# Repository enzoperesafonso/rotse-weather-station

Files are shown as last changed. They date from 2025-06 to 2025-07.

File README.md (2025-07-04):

# Open Observatory Weather Station

Open-source, low-cost weather station designed for remote astronomical observatories

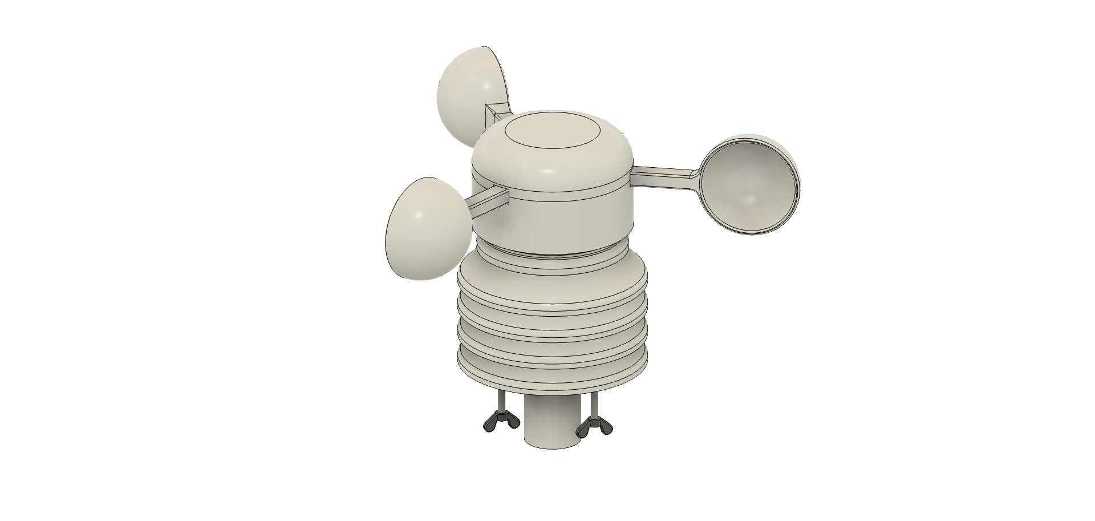
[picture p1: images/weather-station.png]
Weather Station


## Overview

A complete weather monitoring solution built specifically for astronomical observatories and remote telescope installations. This project provides everything needed to build and deploy a professional-grade weather station at a fraction of commercial costs.

Originally developed to support the ROTSE-III Namibia telescope revival project, but designed as a general-purpose solution for the global astronomy community.

## Features

- **Comprehensive Sensor Suite**: Temperature, humidity, barometric pressure, wind speed.
- **3D Printable Design**: Weatherproof enclosure and mounting hardware
- **Remote Monitoring**: Web interface with real-time data display
- **Data Logging**: CSV/JSON export with API access
- **Solar Power Ready**: Designed for off-grid installations
- **Robust Construction**: Built to withstand harsh outdoor environments

## Hardware Design

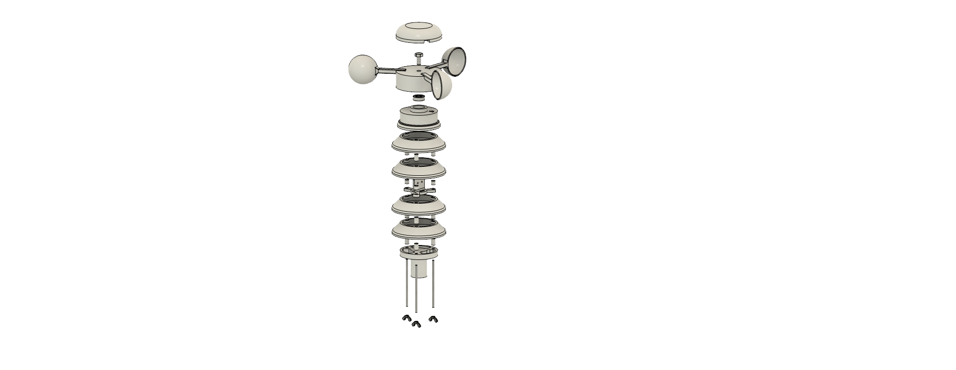
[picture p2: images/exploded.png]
Cutaway View


The weather station features a modular design with a weatherproof 3D printed enclosure. All components are easily accessible for maintenance while providing excellent protection against the elements.

## Quick Start

1. **Hardware**: Print the enclosure parts and assemble with components from the BOM
2. **Software**: Flash the firmware and configure your WiFi settings
3. **Deploy**: Mount securely and connect to your observatory network
4. **Monitor**: Access the web interface for real-time data and historical logs

## Repository Structure

- `hardware/` - 3D models, electronics schematics, and assembly instructions
- `software/` - Firmware, web interface, and calibration tools
- `docs/` - Detailed assembly guide, setup instructions, and troubleshooting
- `examples/` - Sample configurations and data outputs

## Getting Started

See the [Assembly Guide](docs/assembly-guide.md) for detailed build instructions and the [Software Setup](docs/software-setup.md) guide for firmware installation.

## License

This project is open source. See [LICENSE](LICENSE) for details.

## Acknowledgments

This project was developed to support the revival of the ROTSE-III telescope network and is dedicated to making low cost professional-grade weather monitoring accessible to observatories worldwide.

---

⭐ If this project helps your observatory, please consider starring the repository!

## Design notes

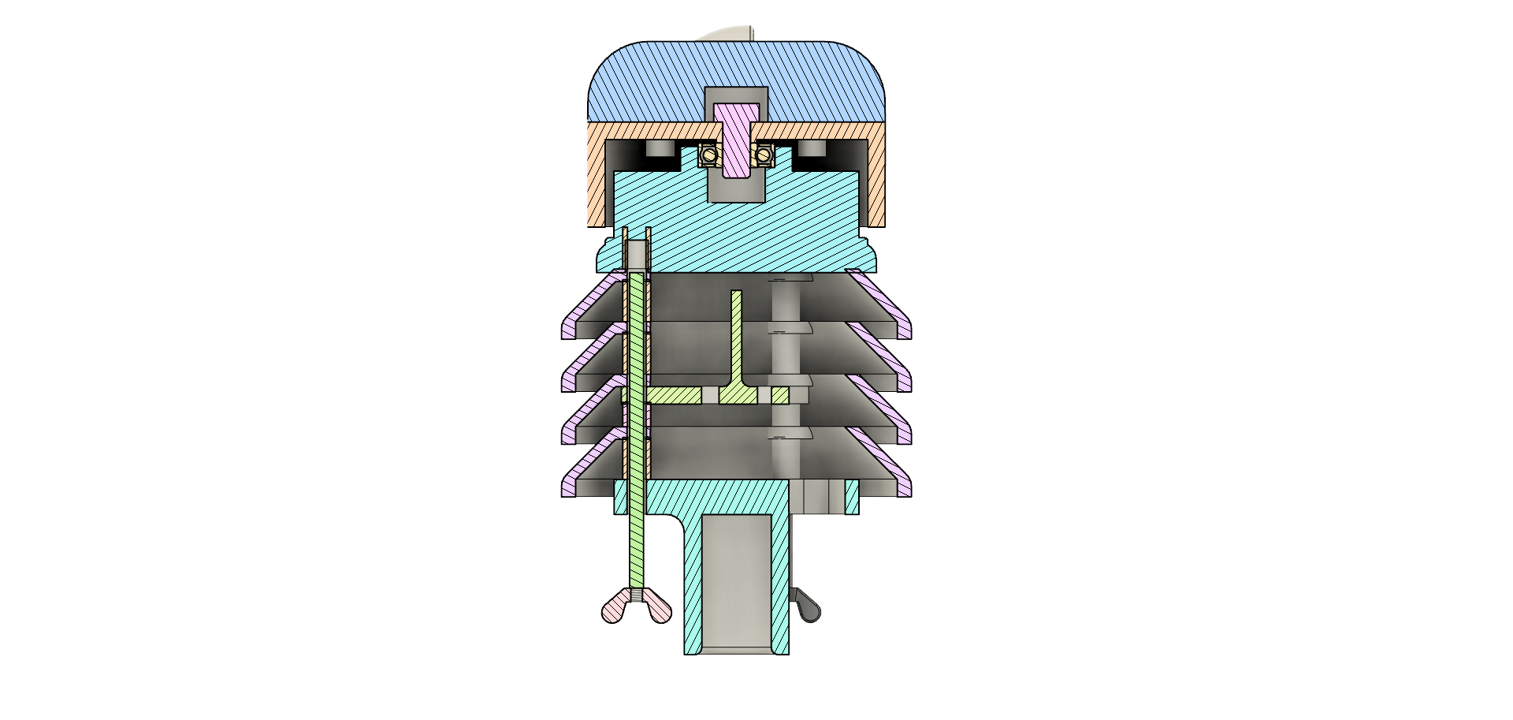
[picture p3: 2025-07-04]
images/cutaway.png

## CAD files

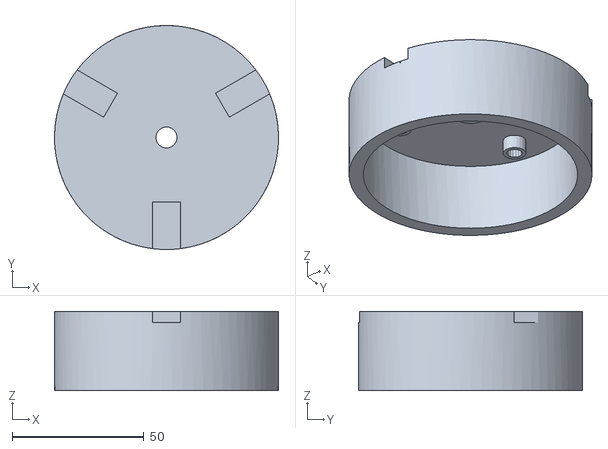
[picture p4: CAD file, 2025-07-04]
hardware/enclosure/3d-print-files/rotor.stl
85.0 x 85.0 x 30.0

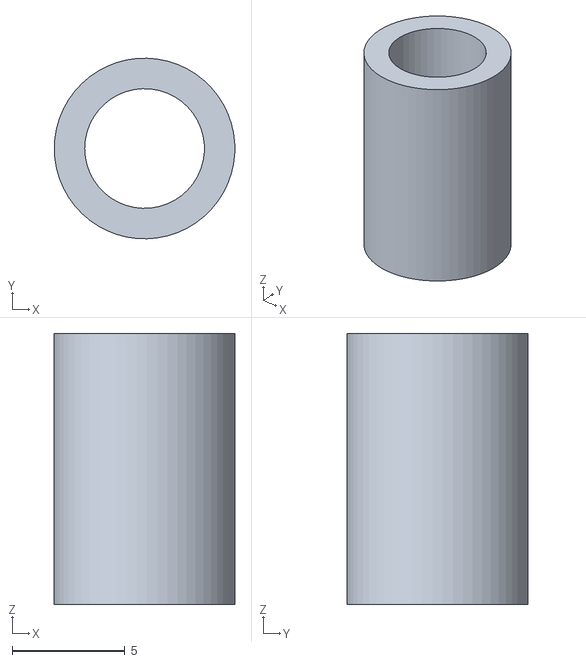
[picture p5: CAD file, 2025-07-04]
hardware/enclosure/3d-print-files/tall-spacer.stl
7.99 x 8.00 x 12.0

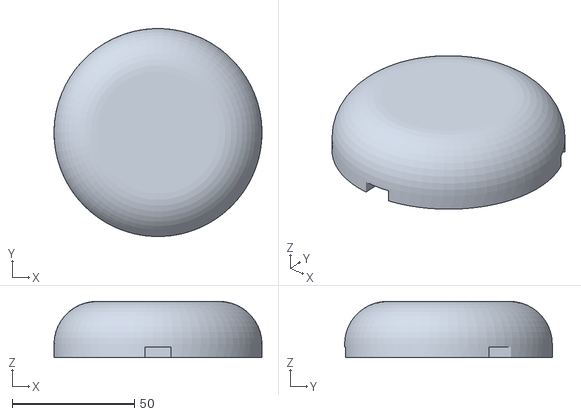
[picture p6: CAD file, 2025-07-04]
hardware/enclosure/3d-print-files/rotor-cap.stl
85.0 x 85.0 x 23.0

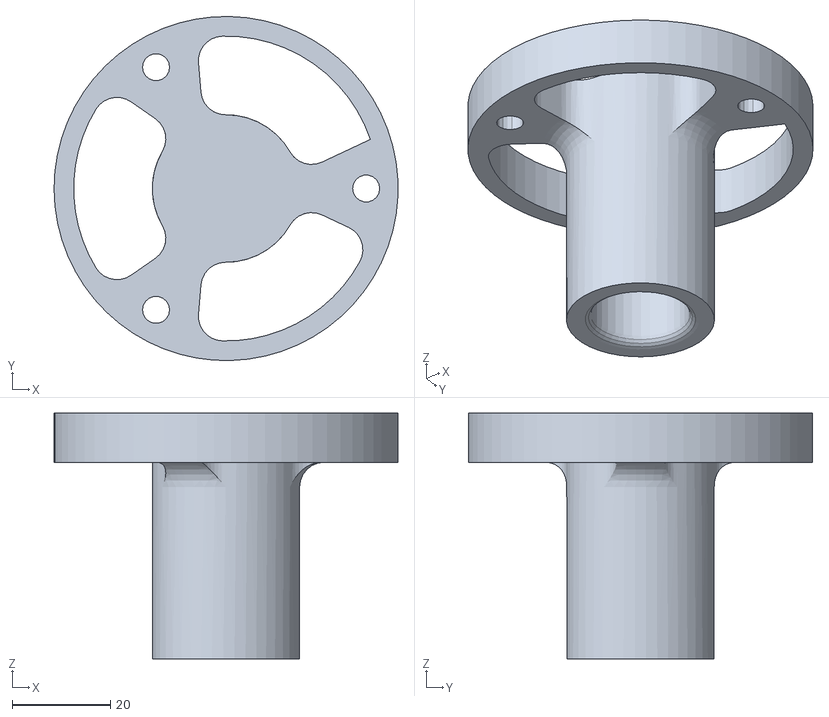
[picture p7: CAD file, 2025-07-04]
hardware/enclosure/3d-print-files/base.stl
70.0 x 70.0 x 50.0

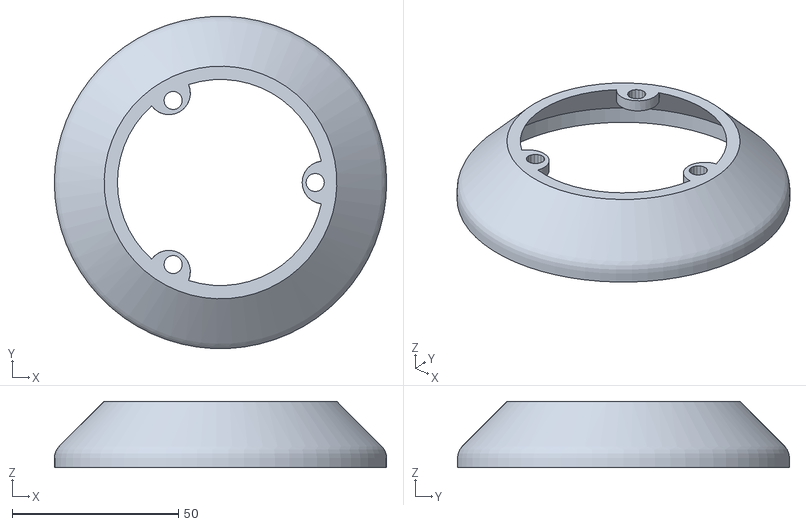
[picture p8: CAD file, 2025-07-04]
hardware/enclosure/3d-print-files/radiation-screen.stl
100.0 x 99.9 x 20.0

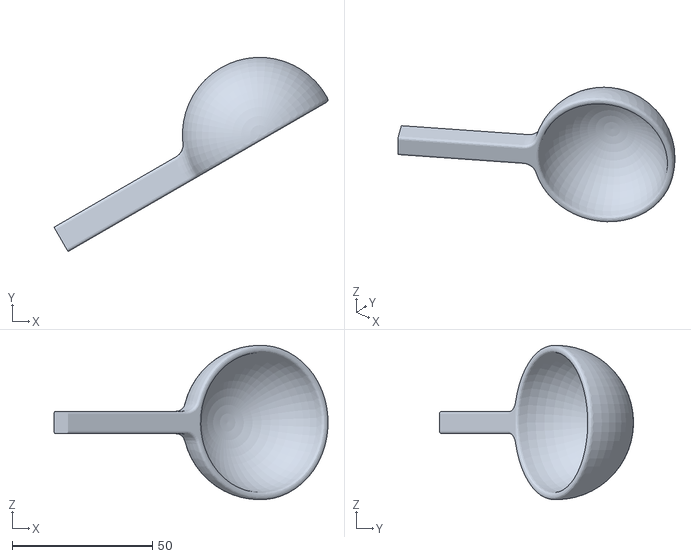
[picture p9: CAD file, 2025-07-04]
hardware/enclosure/3d-print-files/cup.stl
97.7 x 69.2 x 55.0

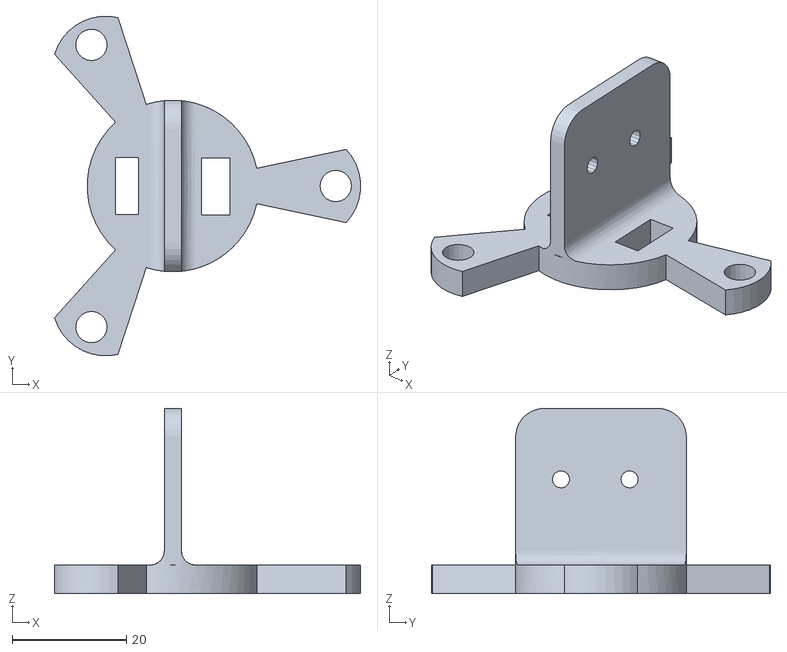
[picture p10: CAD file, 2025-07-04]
hardware/enclosure/3d-print-files/sensor-holder.stl
53.5 x 59.4 x 32.4

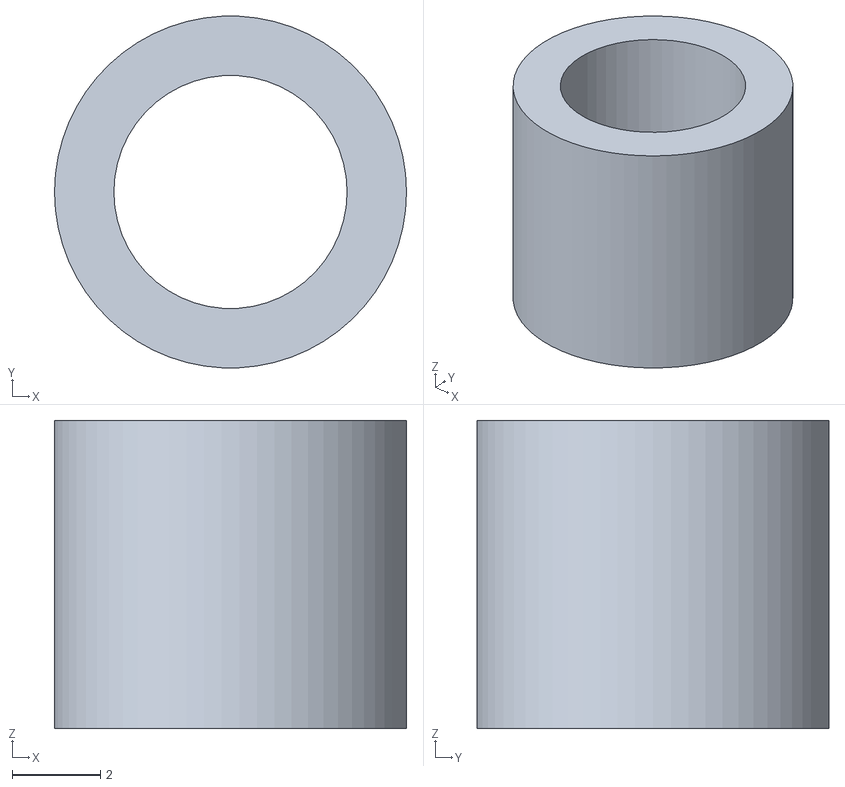
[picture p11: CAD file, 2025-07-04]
hardware/enclosure/3d-print-files/short-spacer.stl
8.00 x 7.99 x 7.00

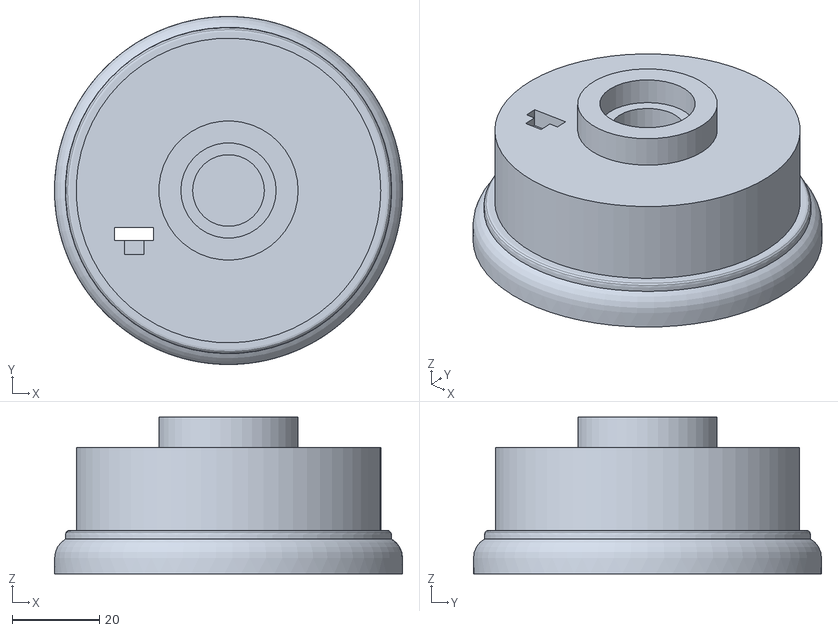
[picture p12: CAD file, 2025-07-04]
hardware/enclosure/3d-print-files/roof.stl
80.0 x 80.0 x 36.0

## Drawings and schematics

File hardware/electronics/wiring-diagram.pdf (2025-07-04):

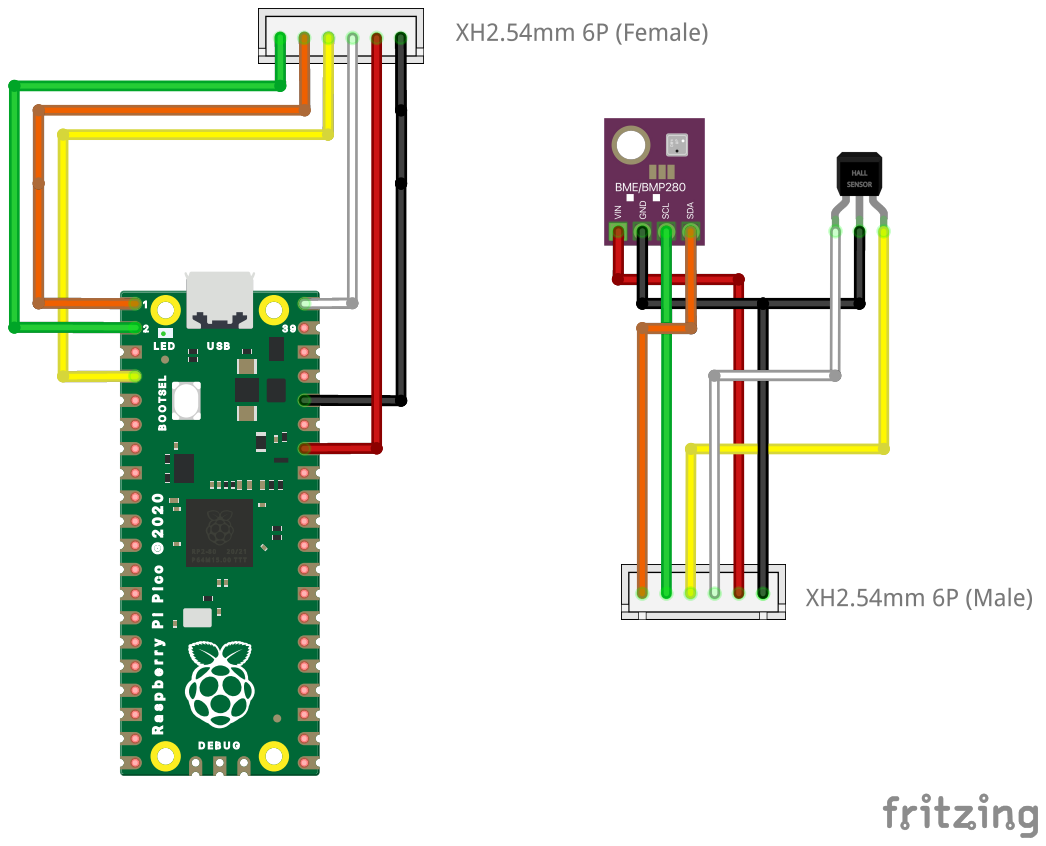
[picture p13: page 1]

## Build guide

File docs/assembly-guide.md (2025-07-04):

# Weather Station Assembly Guide

*Complete hardware and electronics assembly instructions for the Open Observatory Weather Station*

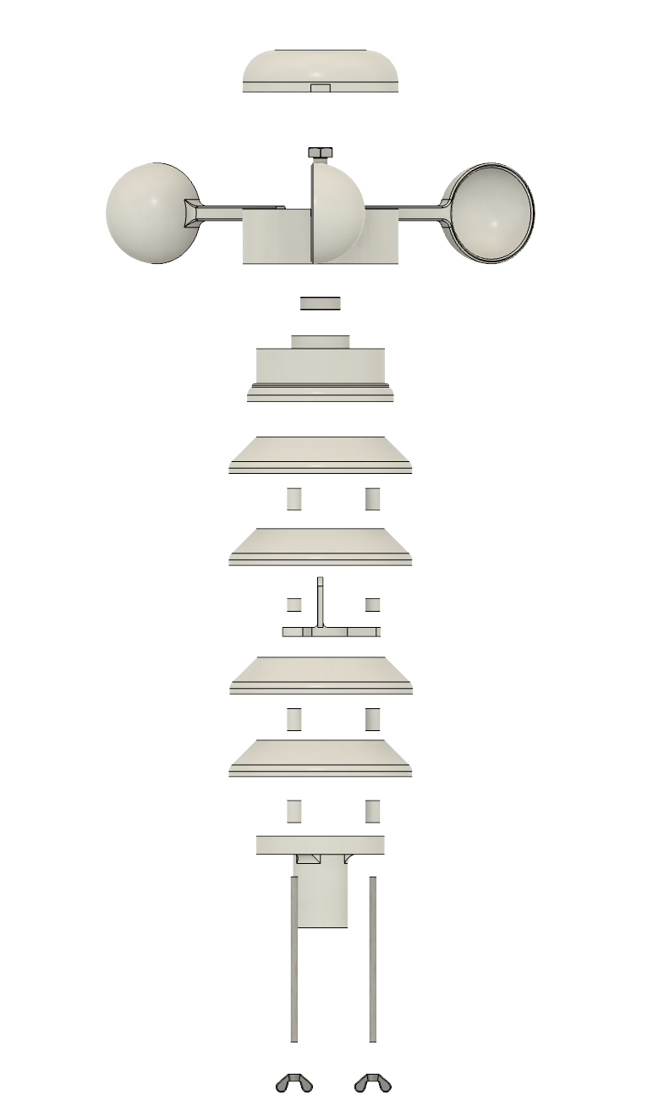
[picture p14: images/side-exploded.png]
ROTSE Weather Station Exploded View


## Bill of Materials

### 3D Printed Parts
- 1x Base
- 1x Roof  
- 1x Sensor Holder
- 4x Radiation Screens
- 1x Rotor
- 1x Rotor Cap
- 3x Cup 
- 12x Tall spacer
- 3x Short spacer

### Hardware Components
- 1x M8 x 16 Steel hex head bolt
- 1x M8 Nut
- 3x M4 Steel wing nuts
- 3x Steel rod M4 (10cm length)
- 1x Ball bearing (permanently lubricated)
- 3x Neodymium magnets (5x5mm)

### Electronics
- 1x Raspberry Pi Pico
- 1x AHT20 + BMP280 Temperature, Humidity, and Pressure Module
- 1x Hall Effect Sensor A3144 
- MicroUSB cable for programming
- 2x XH2.54 4P Male Connector (Recommended)
- 2x XH2.54 4P Female Connector (Recommended)
- 1x Double Side Prototype PCB Universal Printed Circuit Board (3x7cm) (Recommended)
- 4m 6-core cable (Recommended)

## Tools Required
- 3D printer (PLA or PETG recommended)
- Soldering iron and solder
- Wire strippers
- Small screwdriver set
- Drill with small bits
- Multimeter (for testing)

## Assembly Instructions

### Step 1: Rotor Assembly
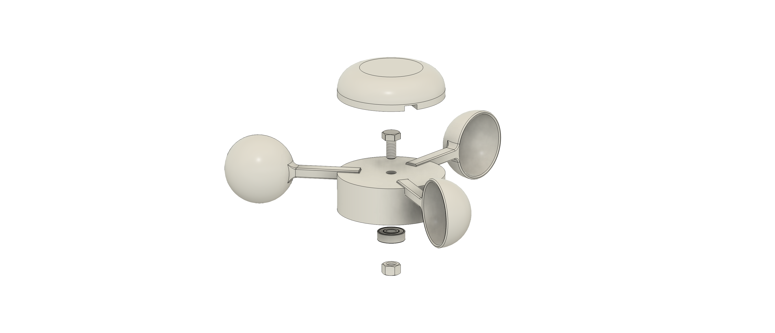
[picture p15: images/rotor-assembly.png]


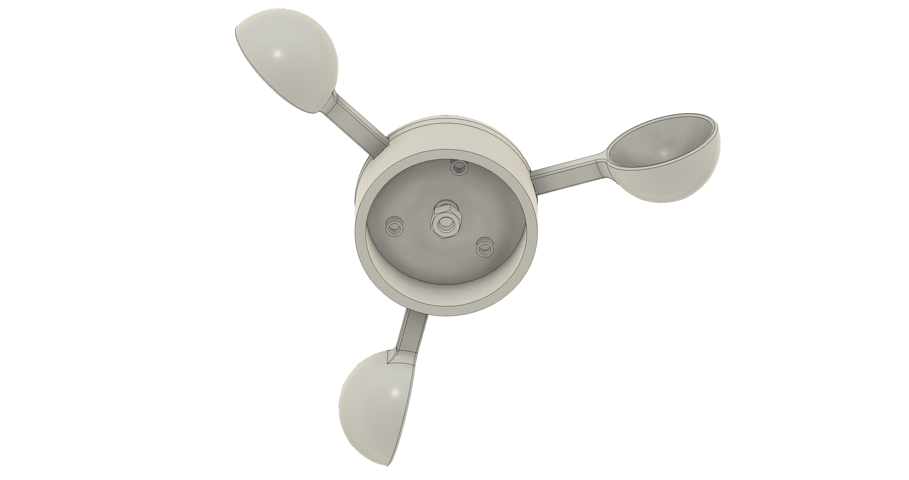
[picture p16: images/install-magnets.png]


### Step 2: Roof
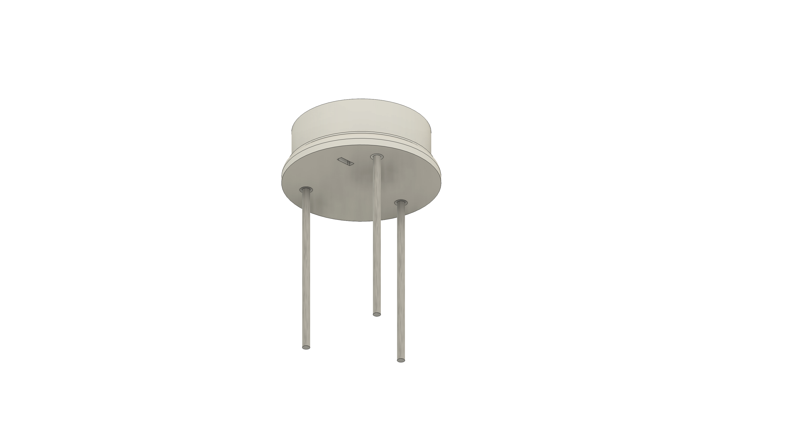
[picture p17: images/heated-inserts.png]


### Step 3: Body
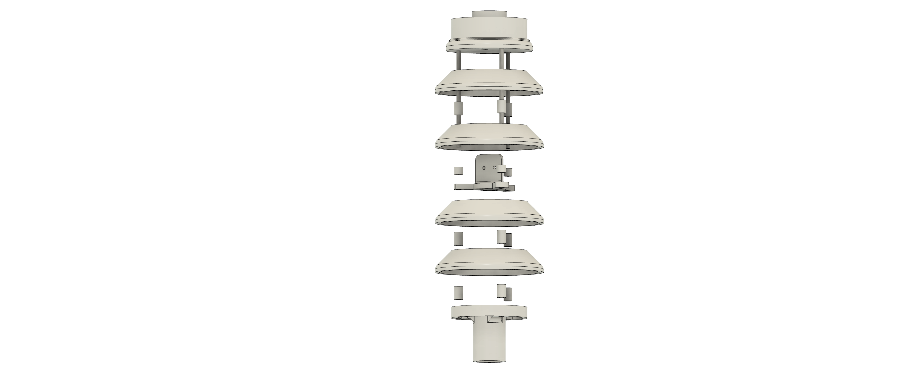
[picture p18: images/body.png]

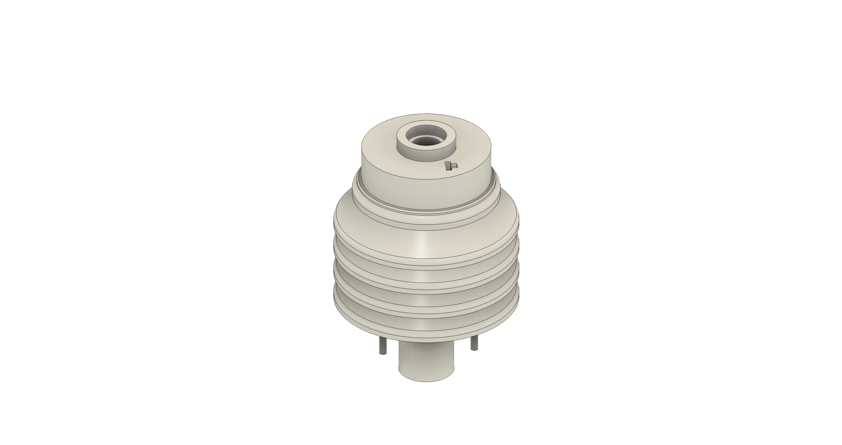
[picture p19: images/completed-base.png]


### Step 4: Finish 
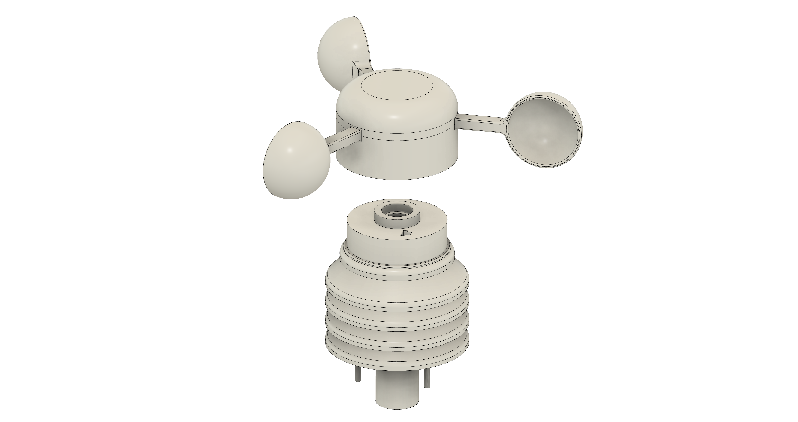
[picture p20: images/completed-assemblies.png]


S

### Step 5: Electronics Assembly

Electronics Wiring Diagram

1. **Prepare the Raspberry Pi Pico**:
   - Install MicroPython or CircuitPython firmware
   - Test basic functionality before installation

2. **Connect the BMP280 sensor**:
   ```
   BMP280 -> Pi Pico
   VCC    -> 3.3V
   GND    -> GND
   SCL    -> GP1 (I2C)
   SDA    -> GP0 (I2C)
   ```

BMP280 Wiring
*[Image suggestion: Photo showing BMP280 sensor wired to Pi Pico with colored wires]*

3. **Wire the Hall effect sensor**:
   ```
   Hall Sensor -> Pi Pico
   VCC        -> 3.3V
   GND        -> GND
   OUT        -> GP2 (Digital input)
   ```

Hall Sensor Wiring
*[Image suggestion: Photo of Hall effect sensor with wiring connections clearly visible]*

4. **Position the Hall effect sensor**:
   - Mount the sensor near the rotor magnet path
   - Ensure it detects magnet passes without interference
   - Test rotation detection before final assembly

Hall Sensor Positioning
*[Image suggestion: Photo showing Hall sensor positioned relative to rotating magnet path]*

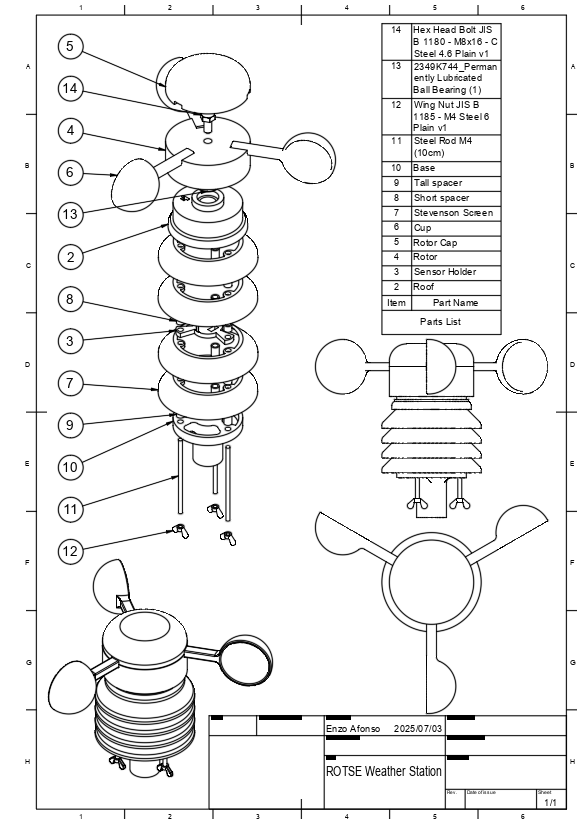
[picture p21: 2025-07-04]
hardware/enclosure/weather-station-instructions.png

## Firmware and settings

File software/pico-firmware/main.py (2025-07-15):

# Enzo Peres Afonso 2025 https://github.com/enzoperesafonso

from machine import Pin, I2C, WDT, disable_irq, enable_irq
import time
import math
from aht20bmp280 import BMP280, AHT20

# === CONFIGURATION ===

# I2C configuration (bus ID and pin numbers)
I2C_BUS_ID = 0
I2C_SCL_PIN = 1
I2C_SDA_PIN = 0

# GPIO pin assignments
HALL_EFFECT_PIN = 2     # Hall sensor input pin
STATUS_LED_PIN = 25      # Onboard LED for status heartbeat

# Anemometer physical properties
MAGNETS_PER_REV = 3                    # Number of magnets attached to the rotor
ANEMOMETER_RADIUS_M = 0.15            # Radius of anemometer (meters)
CIRCUMFERENCE_M = 2 * math.pi * ANEMOMETER_RADIUS_M  # Rotor circumference

# Calibration parameters (derived from actual vs uncalibrated measurements)
CALIBRATION_SLOPE = 2.445645          # Linear slope factor
CALIBRATION_OFFSET = 0         # Linear offset (m/s)

# Timing intervals
REPORT_INTERVAL_MS = 5000             # How often to report data (ms)
DEBOUNCE_MS = 10                      # Debounce time for Hall sensor input (ms)
WATCHDOG_TIMEOUT_MS = 8000           # Watchdog reset interval (ms)

# === I2C and SENSOR SETUP ===

# Initialize I2C bus
i2c = I2C(I2C_BUS_ID, scl=Pin(I2C_SCL_PIN), sda=Pin(I2C_SDA_PIN))

# Initialize sensors
aht = AHT20(i2c)      # Temperature and humidity
bmp = BMP280(i2c)     # Temperature and pressure

# === WIND SPEED VARIABLES ===

pulse_count = 0           # Total magnet pulses detected
last_pulse_time = 0       # Time of last valid pulse (for debouncing)

# === STATUS LED ===

led = Pin(STATUS_LED_PIN, Pin.OUT)  # Onboard LED for visual heartbeat

# === WATCHDOG TIMER ===

wdt = WDT(timeout=WATCHDOG_TIMEOUT_MS)  # Resets system if loop stalls

# === HALL SENSOR INTERRUPT HANDLER ===

def hall_interrupt(pin):
    """Triggered on falling edge of Hall effect signal.
    Debounced to prevent false counts due to mechanical noise."""
    global pulse_count, last_pulse_time
    now = time.ticks_ms()
    if time.ticks_diff(now, last_pulse_time) > DEBOUNCE_MS:
        pulse_count += 1
        last_pulse_time = now

# Setup Hall effect sensor pin with internal pull-up and interrupt
hall = Pin(HALL_EFFECT_PIN, Pin.IN, Pin.PULL_UP)
hall.irq(trigger=Pin.IRQ_FALLING, handler=hall_interrupt)

# === ROLLING AVERAGE BUFFER ===

wind_buffer = []

def get_rolling_avg(new_value, window=5):
    """Maintain a rolling average over 'window' samples."""
    wind_buffer.append(new_value)
    if len(wind_buffer) > window:
        wind_buffer.pop(0)
    return sum(wind_buffer) / len(wind_buffer)

# === WIND SPEED CALIBRATION ===

def calibrate_wind_speed(uncalibrated_speed):
    """Apply linear calibration: calibrated = slope * uncalibrated + offset"""
    return CALIBRATION_SLOPE * uncalibrated_speed + CALIBRATION_OFFSET

# === SENSOR READ WITH VALIDATION AND RETRIES ===

def safe_sensor_read(retries=3):
    """Attempts to read all sensors, retrying on failure.
    Returns placeholder values if all attempts fail."""
    for _ in range(retries):
        try:
            aht_temp, humidity = aht.measure()
            bmp_temp, pressure = bmp.read()
            t_avg = (aht_temp + bmp_temp) / 2
            if is_valid(t_avg, humidity, pressure):
                return t_avg, humidity, pressure
        except Exception:
            time.sleep(0.1)
    return -999, -1, -1  # Error codes

def is_valid(temp, hum, pres):
    """Sanity check for sensor ranges."""
    return -40 <= temp <= 90 and 0 <= hum <= 100 and 300 <= pres <= 1100

# === MAIN LOOP ===

last_report_time = time.ticks_ms()
# print("Weather station started.")
# print("Format: T:temp H:humidity P:pressure WS:wind_speed_ms")

while True:
    # Feed watchdog to avoid reset
    wdt.feed()

    # Toggle status LED to indicate system is alive
    led.toggle()

    current_time = time.ticks_ms()
    
    # Check if it's time to report
    if time.ticks_diff(current_time, last_report_time) >= REPORT_INTERVAL_MS:
        elapsed_seconds = time.ticks_diff(current_time, last_report_time) / 1000.0
        last_report_time = current_time

        # Atomically read and reset pulse counter to avoid race conditions
        state = disable_irq()
        pulses = pulse_count
        pulse_count = 0
        enable_irq(state)

        # Calculate raw wind speed based on counted pulses
        rotations = pulses / MAGNETS_PER_REV
        distance_m = rotations * CIRCUMFERENCE_M
        wind_speed_raw = distance_m / elapsed_seconds if elapsed_seconds > 0 else 0
        
        # Apply calibration to get actual wind speed
        wind_speed_calibrated = calibrate_wind_speed(wind_speed_raw)

        # Smooth wind speed using rolling average
        wind_speed_avg = get_rolling_avg(wind_speed_calibrated)

        # Read temperature, humidity, and pressure
        temp, hum, pres = safe_sensor_read()

        # Print results to serial console
        if temp == -999:
            print(f"T:ERR H:ERR P:ERR WS:{wind_speed_avg:.2f}")
        else:
            print(f"T:{temp:.1f} H:{hum:.1f} P:{pres:.1f} WS:{wind_speed_avg:.2f}")

    # Prevent CPU from spinning at 100% — improves stability
    time.sleep_ms(10)

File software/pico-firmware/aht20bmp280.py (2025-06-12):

# Enzo Peres Afonso 2025 https://github.com/enzoperesafonso

from machine import I2C, Pin
import utime

# --- BMP280 Driver ---
class BMP280:
    """
    MicroPython driver for the BMP280 temperature and pressure sensor.
    """

    def __init__(self, i2c, addr=0x77):
        """
        Initialize the BMP280 sensor.

        :param i2c: Initialized machine.I2C instance.
        :param addr: I2C address of the BMP280 sensor (default 0x77).
        """
        self.i2c = i2c
        self.addr = addr
        self._load_calibration()  # Load factory calibration data from sensor

        # Control measurement register:
        # Normal mode, temperature oversampling x1, pressure oversampling x1
        self.i2c.writeto_mem(self.addr, 0xF4, b'\x27')

        # Configuration register:
        # Standby time = 1000 ms, filter coefficient = 4
        self.i2c.writeto_mem(self.addr, 0xF5, b'\xA0')

    def _read16(self, reg):
        """
        Read an unsigned 16-bit value from two consecutive registers.

        :param reg: Starting register address.
        :return: Unsigned 16-bit integer.
        """
        data = self.i2c.readfrom_mem(self.addr, reg, 2)
        return data[1] << 8 | data[0]

    def _read16s(self, reg):
        """
        Read a signed 16-bit value from two consecutive registers.

        :param reg: Starting register address.
        :return: Signed 16-bit integer.
        """
        val = self._read16(reg)
        return val - 65536 if val > 32767 else val

    def _read24(self, reg):
        """
        Read a 24-bit unsigned value from three consecutive registers.

        :param reg: Starting register address.
        :return: 24-bit unsigned integer.
        """
        data = self.i2c.readfrom_mem(self.addr, reg, 3)
        return (data[0] << 16) | (data[1] << 8) | data[2]

    def _load_calibration(self):
        """
        Load calibration constants from BMP280 non-volatile memory.
        These values are required to compensate raw sensor data.
        """
        self.dig_T1 = self._read16(0x88)
        self.dig_T2 = self._read16s(0x8A)
        self.dig_T3 = self._read16s(0x8C)
        self.dig_P1 = self._read16(0x8E)
        self.dig_P2 = self._read16s(0x90)
        self.dig_P3 = self._read16s(0x92)
        self.dig_P4 = self._read16s(0x94)
        self.dig_P5 = self._read16s(0x96)
        self.dig_P6 = self._read16s(0x98)
        self.dig_P7 = self._read16s(0x9A)
        self.dig_P8 = self._read16s(0x9C)
        self.dig_P9 = self._read16s(0x9E)

    def read(self):
        """
        Read and return compensated temperature and pressure values.

        :return: Tuple of temperature in °C and pressure in hPa.
        """
        # Raw readings
        adc_T = self._read24(0xFA) >> 4
        adc_P = self._read24(0xF7) >> 4

        # Temperature compensation
        var1 = (((adc_T >> 3) - (self.dig_T1 << 1)) * self.dig_T2) >> 11
        var2 = (((((adc_T >> 4) - self.dig_T1) * ((adc_T >> 4) - self.dig_T1)) >> 12) * self.dig_T3) >> 14
        t_fine = var1 + var2
        temperature = ((t_fine * 5 + 128) >> 8) / 100

        # Pressure compensation
        var1_p = t_fine - 128000
        var2_p = var1_p * var1_p * self.dig_P6
        var2_p += (var1_p * self.dig_P5) << 17
        var2_p += self.dig_P4 << 35
        var1_p = ((var1_p * var1_p * self.dig_P3) >> 8) + ((var1_p * self.dig_P2) << 12)
        var1_p = (((1 << 47) + var1_p) * self.dig_P1) >> 33

        if var1_p == 0:
            pressure = 0  # Avoid division by zero
        else:
            p = 1048576 - adc_P
            p = ((p << 31) - var2_p) * 3125 // var1_p
            var1_p = (self.dig_P9 * (p >> 13) * (p >> 13)) >> 25
            var2_p = (self.dig_P8 * p) >> 19
            pressure = ((p + var1_p + var2_p) >> 8) / 25600

        return temperature, pressure


# --- AHT20 Driver ---
class AHT20:
    """
    MicroPython driver for the AHT20 temperature and humidity sensor.
    """

    def __init__(self, i2c, addr=0x38):
        """
        Initialize the AHT20 sensor and perform initial calibration.

        :param i2c: Initialized machine.I2C instance.
        :param addr: I2C address of the AHT20 (default 0x38).
        """
        self.i2c = i2c
        self.addr = addr
        self._init_sensor()

    def _init_sensor(self):
        """
        Send initialization command to the AHT20 sensor.
        """
        self.i2c.writeto(self.addr, b'\xE1\x08\x00')
        utime.sleep_ms(40)  # Allow time for initialization

    def _read_status(self):
        """
        Read the status byte from the sensor.

        :return: Single byte representing sensor status.
        """
        return self.i2c.readfrom(self.addr, 1)[0]

    def measure(self):
        """
        Trigger a measurement and return temperature and humidity readings.

        :return: Tuple of temperature in °C and humidity in %RH.
        """
        self.i2c.writeto(self.addr, b'\xAC\x33\x00')
        utime.sleep_ms(80)  # Wait for measurement cycle

        # Wait until busy bit (bit 7) clears
        while self._read_status() & 0x80:
            utime.sleep_ms(10)

        data = self.i2c.readfrom(self.addr, 6)

        # Parse measurement data
        raw_humidity = ((data[1] << 12) | (data[2] << 4) | (data[3] >> 4))
        raw_temperature = ((data[3] & 0x0F) << 16) | (data[4] << 8) | data[5]

        # Convert to physical values
        humidity = (raw_humidity * 100) / 1048576
        temperature = ((raw_temperature * 200) / 1048576) - 50

        return temperature, humidity

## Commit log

2025-07-04 added 3d files
    [Base.stl, Cup.stl, Radiation Screen.stl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]
2025-07-04 renamed components
    [radiation-screen.stl, rotor-cap.stl, sensor-holder.stl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]
2025-07-04 started documenation
    [base.stl, cup.stl, radiation-screen.stl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]
